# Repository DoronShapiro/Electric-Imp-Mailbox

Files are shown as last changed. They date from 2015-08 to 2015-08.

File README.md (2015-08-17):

# Electric Imp Mailbox Sensor

The Electric Imp mailbox sensor is a prototype smart mailbox module designed to be placed in existing mailboxes.  This device can sense when mail deliveries occur, identify NFC-tagged mail, and trigger push notifications.

The goal of this project was to follow the process of quickly prototyping an internet-connected device for production using the Electric Imp platform.  This was also an opportunity to test two new pieces of hardware at Electric Imp: the PN532 NFC module and the TMD2772 Proximity/Ambient light sensor.

## Hardware

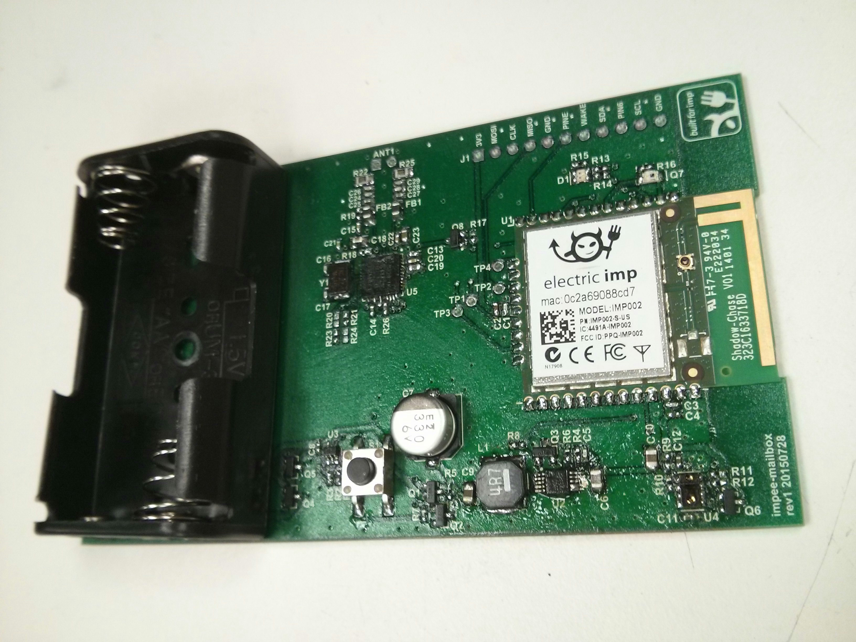
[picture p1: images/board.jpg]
Assembled circuit board


The mailbox sensor has the following features:

- **Powered by 2xAA batteries** with voltage sense for low-battery notifications
- **Ambient light and proximity sensing** using a [TMD2772](https://ams.com/jpn/content/download/685865/1786649/file/TMD2772WA_Datasheet-%5B1-20%5D.pdf) sensor.  This sensor is used to determine if the mailbox is open and if it contains mail.  It was chosen for having programmable interrupts and containing an IR LED in its package that reduced power usage and lowered the final part count.
- **NFC read/write** using the [PN532](http://www.nxp.com/products/identification_and_security/nfc_and_reader_ics/nfc_controller_solutions/PN5321A3HN.html) NFC controller and an external antenna.  The external antenna was an experimental feature and was designed to allow the device to work in different mailbox configurations (e.g. vertical or horizontal).
- **Processing and wifi** using an [imp002](https://electricimp.com/docs/attachments/hardware/product%20briefs/Electric%20Imp%20-%20imp002%20-%20Product%20Brief%20-%2022Jun2015.pdf) solder-down module
- **I²C, SPI, UART, and interrupt breakouts** for offline debugging and further hacking

The device schematic, Altium project files, generated Gerber files, and BOM can be found in the project [hardware files](./hardware/).

## Software

The software running the device makes extensive use of Electric Imp [software libraries](https://electricimp.com/docs/examples/libraries/) to simplify the codebase.  These classes include pre-tested device drivers and abstractions surrounding common tasks and make it easy to begin designing application logic even before prototype hardware has been manufactured.

### Device-Side

This project used the device driver libraries for the [TMD2772](https://electricimp.com/docs/libraries/hardware/tmd2772.1.0.0/) and [PN532](https://electricimp.com/docs/libraries/hardware/pn532.1.0.0/) modules, as well as a library for advanced [wifi connection management](https://github.com/electricimp/ConnectionManager) that allows the device to conserve power by aggresively staying offline.

The complete device code can be found in the project [software files](./software/mailbox.device.nut).

### Agent-Side

The agent uses the [Rocky](https://electricimp.com/docs/libraries/utilities/rocky.1.2.0/) library to create a REST API for registering expected mail and the [IFTTT](https://github.com/electricimp/IFTTT) library to trigger push notifications when mail arrives.

The complete agent code can be found in the project [software files](./software/mailbox.agent.nut).

## Usage
The device is designed to be small enough to placed in the back of a mailbox.  To extend battery life, it spends most of its time in a low-power sleep mode.  When the mailbox door opens, the resulting light wakes the device.  It checks for the presence of mail using the proximity sensor and if it is found, begins an NFC scan to check for NFC-tagged mail.  Finally, once the scan is complete, it pushes the result to a phone running the [IFTTT app](https://ifttt.com/products#if).

When mail is sent to a mailbox owner, a [cheap NFC tag](http://nfctags.tagstand.com/collections/nfc-stickers/products/the-25-25-25-roll-of-2500-ntag213-stickers) can be added to the mail and then registered with the recipient using a REST API. When tagged mail is received, the device checks if it has been registered and if so, can notify both the sender and receiver of the event.

## Known Issues

### V1:
- Q6 is reversed (fixed in V2)
- The `BAT+` net should be connected to the Imp's Pin A instead of Pin C in order to be accesible to an ADC (fixed in V2)

## License
This project is licensed under the [MIT License](./LICENSE).

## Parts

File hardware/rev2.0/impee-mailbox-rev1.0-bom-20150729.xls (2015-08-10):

impee-mailbox.PrjPCB
Bill of Materials
Electric Imp, Inc
1.0
7/29/2015 |  |  | 10:30:50 AM
# | Part Number | Designator | Quantity | Description | Manufacturer | Manufacturer Part Number | Manufacturer 2 | Manufacturer Part Number 2 | Supplier 1 | Supplier Part Number 1 | Supplier Price 1 | Supplier 2 | Supplier Part Number 2 | Supplier Price 2 | Extended Price
1 | BAT00006 | BAT1 | 1 | 2xAA Series Battery Clip with Through-Hole PCB Mount | Eagle Plastic Devices | 12BH321P-GR |  |  | Mouser | 12BH321P-GR | 0.33 |  |  |  | 0.33
2 | CAPC00043 | C1, C3, C26, C29 | 4 | CAP,C0G,100pF,5%,50V,0402 | Yageo | CC0402JRNPO9BN101 | Samsung | CL05C101JB5NNNC | Digi-Key | 311-1024-1-ND | 0.00324 | Digi-Key | 1276-1025-1-ND | 0.00324 | 0.01296
3 | CAPC00005 | C2, C4, C8, C11, C12, C13, C14 | 7 | CAP,X5R,1.0uF,10%,6.3V, 0402,# | Murata | GRM155R60J105KE19D | Samsung | CL05A105KQ5NNNC | Digi-Key | 490-1320-1-ND | 0.0087 | Digi-Key | 1276-1010-1-ND | 0.009 | 0.0609
4 | CAPC00041 | C5 | 1 | CAP,C0G,12pF,5%,50V,0402# | Yageo | CC0402JRNPO9BN120 | Murata | GRM1555C1H120JZ01D | Digi-Key | 311-1016-1-ND | 0.00324 | Digi-Key | 490-1279-1-ND | 0.00525 | 0.00324
5 | CAPC00039 | C6 | 1 | CAP,X5R,22uF,10%,6.3V,0805,# | TDK | C2012X5R0J226K/1.25 | Taiyo Yuden | JMK325BJ226KM-T | Digi-Key | 445-7679-1-ND | 0.225 | Digi-Key | 587-1471-2-ND | 0.2288 | 0.225
6 | CAPC00106 | C7 | 1 | CAP,Alum,330uF,20%,6.3V,SMD | Nichicon | UWX0J331MCL1GB |  |  | Digi-Key | 493-2091-1-ND | 0.1015 |  |  |  | 0.1015
7 | CAPC00036 | C9, C10 | 2 | CAP,X5R,10uF,10%,6.3V,0805,# | Yageo | CC0805KKX5R5BB106 | Taiyo Yuden | JMK212BJ106KD-T | Digi-Key | 311-1459-1-ND | 0.03399 | Digi-Key | 587-1304-1-ND | 0.0408 | 0.06798
8 | CAPC00092 | C15 | 1 | CAP,X7R,1000pF,10%,50V,0402 | Samsung | CL05B102KB5NCNC | Yageo | CC0402KRX7R7BB102 | Digi-Key | 1276-1492-1-ND | 0.00279 | Digi-Key | 311-1352-1-ND | 0.00309 | 0.00279
9 | CAPC00044 | C16, C17 | 2 | CAP,C0G,27pF,5%,50V,0402 | Yageo | CC0402JRNPO9BN270 | Murata | GRM1555C1H270JA01D | Digi-Key | 311-1019-1-ND | 0.00324 | Digi-Key | 490-5869-1-ND | 0.00525 | 0.00648
10 | CAPC00023 | C18 | 1 | CAP,X7R,0.1uF,10%,50V,0805 | AVX | 08055C104K | Yageo | CC0805KRX7R9BB104 | Mouser | 581-08055C104K | 0.012 | Digi-Key | 311-1140-1-ND | 0.01257 | 0.012
11 | CAPC00033 | C19, C23 | 2 | CAP,X5R,4.7uF,10%,6.3V,0603,# | Taiyo Yuden | JMK107BJ475KA-T | Yageo | CC0603KRX5R5BB475 | Digi-Key | 587-1785-1-ND | 0.02475 | Digi-Key | 311-1521-1-ND | 0.02899 | 0.0495
12 | CAPC00002 | C20, C21, C22 | 3 | CAP,X5R,0.1uF,10%,6.3V, 0402,# | TDK | C1005X5R0J104K | Murata | GRM155R60J104KA01D | Digi-Key | 445-1266-1-ND | 0.0066 | Mouser | 81-GRM155R60J104KA1D | 0.007 | 0.0198
13 | CAPC00045 | C24, C28 | 2 | CAP,C0G,56pF,5%,50V,0402 | Yageo | CC0402JRNPO9BN560 | TDK | C1005C0G1H560J | Digi-Key | 311-1022-1-ND | 0.00324 | Digi-Key | 445-1244-1-ND | 0.006 | 0.00648
14 | CAPC00110 | C25, C27 | 2 | CAP,C0G,220pF,25%,50V,0402 | Samsung | CL05C221JB5NNNC | Taiyo Yuden | UMK105CG221JV-F | Digi-Key | 1276-1059-1-ND | 0.0051 | Digi-Key | 587-1215-1-ND | 0.0051 | 0.0102
15 | LED00012 | D1 | 1 | LED, Red and Green, 2/2V, 631/571nm, 25/35mcd, SMT | Liteon | LTST-C195KGJRKT |  |  | Digi-Key | 160-1452-1-ND | 0.1206 |  |  |  | 0.1206
16 | FB00008 | FB1, FB2 | 2 | FERR BD, 25 Ohm @ 25Mhz, 150mA, 550 mOhm, 0805 | TDK | MLF2012DR56KT000 |  |  | Digi-Key | 445-1044-1-ND | 0.09568 |  |  |  | 0.19136
17 | IND00007 | L1 | 1 | IND, 4.7uH, 20%, 2.7A Isat, 403 mOhm, 6028 | Taiyo Yuden | NR6028T4R7M |  |  | Digi-Key | 587-2100-1-ND | 0.15525 |  |  |  | 0.15525
18 | PFET00009 | Q1, Q6, Q8 | 3 | PFET, 20V, 820mA, 1V, SOT323 | Diodes Inc | DMG1013UW |  |  | Digi-key | DMG1013UW-7DICT-ND | 0.06575 |  |  |  | 0.19725
19 | NFET00004 | Q2, Q4, Q5 | 3 | NFET, 20V, 4.2A, SOT23 | Diodes Incorporated | DMN2075U-7 |  |  | Digi-Key | DMN2075U-7DICT-ND | 0.08295 |  |  |  | 0.24885
20 | NFET00003 | Q3 | 1 | NFET, 25V, 220mA, SOT23 | Fairchild | FDV301N |  |  | Digi-key | FDV301NCT-ND | 0.04155 |  |  |  | 0.04155
21 | PHOTO00002 | Q7 | 1 | Phototrans, Clear, Top View, 940nm, 0.4V, 1mA, 0805 | Everlight | PT17-21C/L41/TR8 |  |  | Digi-Key | 1080-1382-1-ND | 0.07101 |  |  |  | 0.07101
22 | RES00009 | R1 | 1 | RES,470K,5%,0.063W,0402 | Yageo | RC0402JR-07470KL | ROHM | MCR01MRTJ474 | Digi-Key | 311-470KJRCT-ND | 0.00237 | Digi-Key | RHM470KCECT-ND | 0.00352 | 0.00237
23 | RES00008 | R2, R5 | 2 | RES,47K,5%,0.063W,0402 | Yageo | RC0402JR-0747KL | ROHM | MCR01MRTJ473 | Digi-Key | 311-47KJRCT-ND | 0.00237 | Digi-Key | RHM47KCECT-ND | 0.00352 | 0.00474
24 | RES00054 | R3 | 1 | RES,560K,1%,0.063W,0402 | Yageo | RC0402FR-07560KL | Panasonic | ERJ-2RKF5603X | Digi-Key | 311-560KLRCT-ND | 0.0027 | Digi-Key | P560KLCT-ND | 0.00672 | 0.0027
25 | RES00015 | R4 | 1 | RES,270K,5%,0.063W,0402 | Yageo | RC0402JR-07270KL | ROHM | MCR01MZPJ274 | Digi-Key | 311-270KJRDKR-ND | 0.00237 | Digi-Key | RHM270KJCT-ND | 0.00384 | 0.00237
26 | RES00041 | R6 | 1 | RES,43K,1%,0.063W,0402 | Yageo | RC0402FR-0743KL | Rohm | MCR01MZPF4302 | Digi-Key | 311-43.0KLRCT-ND | 0.0027 | Digi-Key | RHM43.0KLCT-ND | 0.00544 | 0.0027
27 | RES00001 | R7, R8, R12, R17, R21, R23 | 6 | RES,100K,5%,0.063W,0402,# | Samsung | RC1005J104CS | ROHM | MCR01MRTJ104 | Digi-Key | 1276-4424-1-ND | 0.0023 | Digi-Key | HM100KCECT-ND | 0.00233 | 0.0138
28 | RES00060 | R9 | 1 | RES,22 Ohm,5%,0.063W,0402 | Yageo | RC0402JR-0722RL | Stackpole | RMCF0402JT22R0 | Digi-Key | 311-22JRCT-ND | 0.00237 | Digi-Key | RMCF0402JT22R0CT-ND | 0.00256 | 0.00237
29 | RES00005 | R10, R11, R26 | 3 | RES,4.7K,5%,0.063W,0402,# | Yageo | RC0402JR-074K7L | ROHM | MCR01MRTJ472 | Digi-Key | 311-4.7KJRCT-ND | 0.00237 | Digi-Key | RHM4.7KCECT-ND | 0.00352 | 0.00711
30 | RES00024 | R13, R14 | 2 | RES,100,1%,0.063W,0402,# | Yageo | RC0402FR-07100RL | ROHM | MCR01MRTF1000 | Digi-Key | 311-100LRCT-ND | 0.0027 | Digi-Key | RHM100CDCT-ND | 0.0048 | 0.0054
31 | RES00006 | R15 | 1 | RES,10k,5%,0.063W,0402,# | Stackpole | RMCF0402JT10K0 | ROHM | MCR01MRTJ103 | Digi-Key | RMCF0402JT10K0CT-ND | 0.00256 | Digi-Key | RHM10KCECT-ND | 0.00352 | 0.00256
32 | RES00007 | R16 | 1 | RES,22K,5%,0.063W,0402 | Yageo | RC0402JR-0722KL | Panasonic | ERJ-2GEJ223X | Digi-Key | 311-22KJRCT-ND | 0.00237 | Digi-Key | P22KJCT-ND | 0.0048 | 0.00237
33 | RES00003 | R18 | 1 | RES,1K,5%,0.063W,0402,# | Yageo | RC0402JR-071KL | ROHM | MCR01MZPJ102 | Digi-Key | 311-1.0KJRCT-ND | 0.00237 | Digi-Key | RHM1.0KJCT-ND | 0.00384 | 0.00237
34 | RES00100 | R19 | 1 | RES,1.5K Ohm,1%,0.063W,0402 | Rohm | MCR01MRTF1501 |  |  | Digi-Key | RHM1.50KCDCT-ND | 0.00233 |  |  |  | 0.00233
35 | RES00018 | R22, R25 | 2 | RES,1 Ohm,1%,0.25W,0805 | ROHM | MCR10ERTFL1R00 | Stackpole | CSR0805FK1R00 | Digi-Key | RHM1.00CICT-ND | 0.0459 | Digi-Key | CSR0805FK1R00CT-ND | 0.074 | 0.0918
36 | BTN00001 | S1 | 1 | SPST- NO Momentary Button, 160g Force, SMD | TE Connectivity | FSM4JSMA |  |  | Digi-Key | 450-1129-ND | 0.0917 |  |  |  | 0.0917
37 | MOD00002 | U1 | 1 | Module, Electric Imp Solder Down with Antenna | Electric Imp | IMP002 |  |  | Digi-Key | 1413-1001-1-ND | 24.1001 |  |  |  | 24.1001
38 | IC00026 | U2 | 1 | IC, DC/DC boost,Adjustable, 6 VIN, 500mA, MSOP10 | Torex | XC9128B45CAR-G | Torex | XC9128D45CAR-G | Digi-Key | 893-1104-1-ND | 0.882 |  |  |  | 0.882
39 | IC00032 | U3 | 1 | IC, Comparator with Reference and Programmable Hysteresis, SOT-353 | Micrel | MIC841HYC5 |  |  | Digi-Key | 576-2923-1-ND | 0.504 |  |  |  | 0.504
40 | IC00196 | U4 | 1 | IC, Sensor, ALS and Proximity, I2C | AMS | TMD27721 |  |  | Digi-Key | TMD27721CT-N | 1.3248 |  |  |  | 1.3248
41 | IC00195 | U5 | 1 | IC, NFC Reader, QFN40 | NXP | PN5321A3HN/C106 |  |  | Digi-Key | 568-8600-ND | 5.03119 |  |  |  | 5.03119
42 | XTAL00003 | Y1 | 1 | XTAL, 27.12MHz, 30ppm, 18pF, 50 Ohm, 5032 | TXC | 7A-27.120MAAJ-T |  |  | Digi-Key | 887-1419-2-ND | 0.35 |  |  |  | 0.35
 |  |  |  |  |  |  |  |  |  |  |  |  |  | Total Price | 34.36348

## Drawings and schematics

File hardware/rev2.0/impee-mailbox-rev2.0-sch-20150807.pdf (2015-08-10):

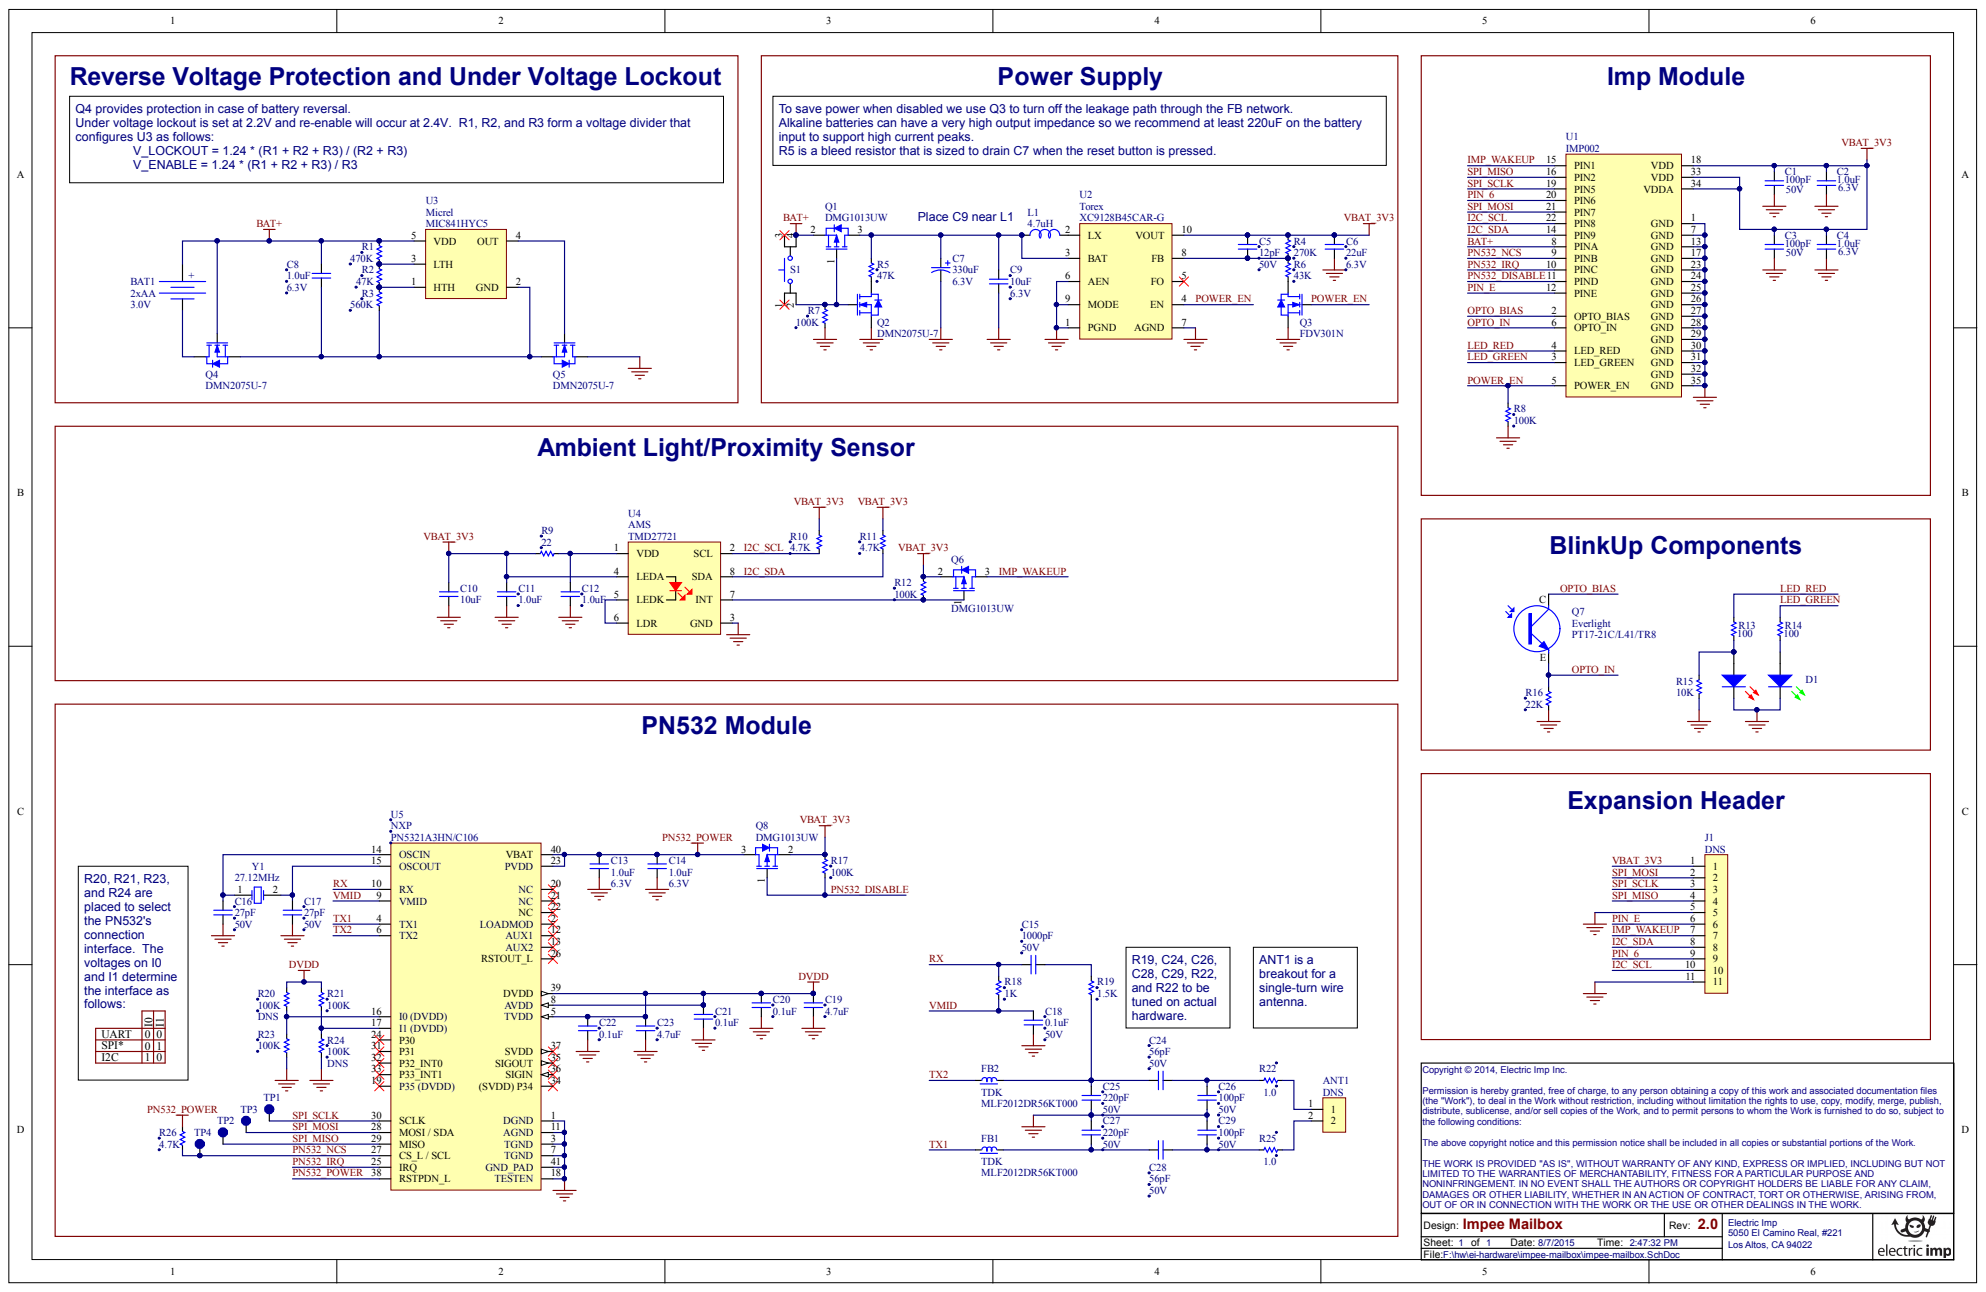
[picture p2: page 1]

Reverse Voltage Protection and Under Voltage Lockout

Q4 provides protection in case of battery reversal.
Under voltage lockout is set at 2.2V and re-enable will occur at 2.4V. R1, R2, and R3 form a voltage divider that
configures U3 as follows:

To save power when disabled we use Q3 to turn off the leakage path through the FB network.
Alkaline batteries can have a very high output impedance so we recommend at least 220uF on the battery
input to support high current peaks.
R5 is a bleed resistor that is sized to drain C7 when the reset button is pressed.

Ambient Light/Proximity Sensor

Copyright © 2014, Electric Imp Inc.

Permission is hereby granted, free of charge, to any person obtaining a copy of this work and associated documentation files
(the "Work"), to deal in the Work without restriction, including without limitation the rights to use, copy, modify, merge, publish,
distribute, sublicense, and/or sell copies of the Work, and to permit persons to whom the Work is furnished to do so, subject to
the following conditions:

The above copyright notice and this permission notice shall be included in all copies or substantial portions of the Work.

THE WORK IS PROVIDED "AS IS", WITHOUT WARRANTY OF ANY KIND, EXPRESS OR IMPLIED, INCLUDING BUT NOT
LIMITED TO THE WARRANTIES OF MERCHANTABILITY, FITNESS FOR A PARTICULAR PURPOSE AND
NONINFRINGEMENT. IN NO EVENT SHALL THE AUTHORS OR COPYRIGHT HOLDERS BE LIABLE FOR ANY CLAIM,
DAMAGES OR OTHER LIABILITY, WHETHER IN AN ACTION OF CONTRACT, TORT OR OTHERWISE, ARISING FROM,
OUT OF OR IN CONNECTION WITH THE WORK OR THE USE OR OTHER DEALINGS IN THE WORK.

Design:
File:
F:\hw\ei-hardware\impee-mailbox\impee-mailbox.SchDoc
